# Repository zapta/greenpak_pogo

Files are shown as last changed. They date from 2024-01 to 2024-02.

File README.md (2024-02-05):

# GreenPAK Programming Pogo Probe

This project provides a standard footprint and a Pogo Probe for in-circuit programming of Renesas GreenPAK 
devices. This can be used for example in production after populating the board with factory reset GreenPAK devices.

<br>

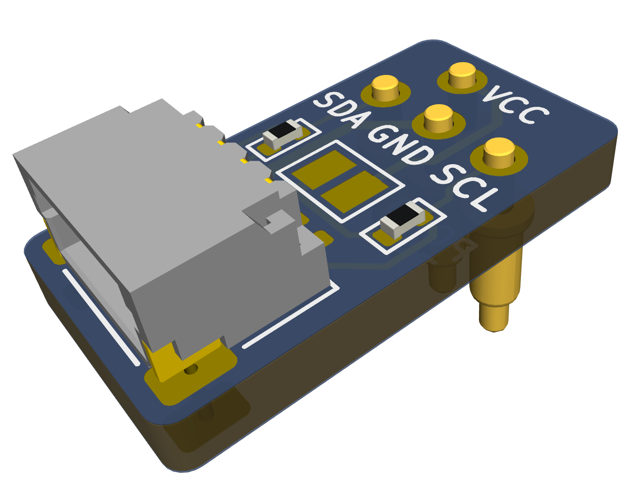
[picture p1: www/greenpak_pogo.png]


Highlights:

* Small footprint.
* In expensive (e.g. compared to Tag Connect)
* Can be used with any QWIIC masters as a probrammer.
* Can provide power to the programmed device.
* A single programming socket can support multiple GreenPAK devices on the same board.

# Schematic

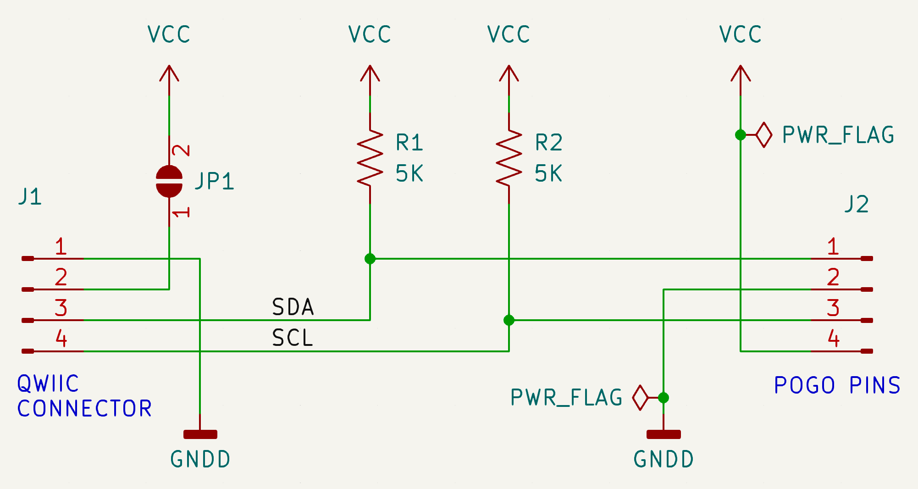
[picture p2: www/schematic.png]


# Pogo pins

We use common pogo pins from Aliexpress, the 5mm ones from https://www.aliexpress.us/item/3256803830386881.html. The diagram belows shows the advertised dimensions on Aliexpress, note that there are two 3.5mm dimensions, the longer of the two is actually 5mm. Also, the diameter of the base is 2mm.

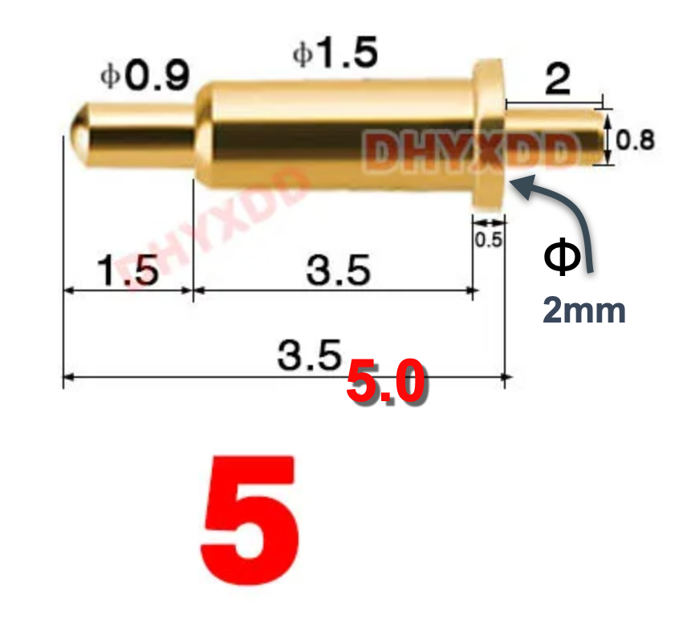
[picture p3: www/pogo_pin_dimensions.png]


# Connector

The connector is JST SH 1.0mm 4pin, SMD, horizontal, and is common on Aliexpress as well as short cables with matching QWIIC connectors on both ends. This is the same connector that is used by the QWIIC and STEMMA QT eco system and follows their pinout.  

| :warning: WARNING          |
|:---------------------------|
| The connecor follows the QWIIC pinout conventions and which are different from the pinout of the Renesas programmer.  If you are using the Pogo Probe with the Renesas programmer, pay attention to the wiring.    |

# Power jumper

The solder jumper on the Pogo Probe allows to connect or disconnect the VCC power of the programmer and the programmed board. By default it's disconnected and if needed, you can connect it with a drop of solder. 

# Pullup resistors

The Pogo Probe has two footprints for pullup resistors for the SDA and SCL signals respectivly. Populating them with 5K to 10K 0402 resistors should work well in most cases. If the circuit being programmed or the I2C master used to program already contain pullup resistors (it should, since the SDA and SCL GreenPAK inputs are not pulled up internally), they can be ommited.

# Programming socket

Kicad comaptible symbol and footprint for the programming socket are available in the kicad directory of this repository.

<br>

Schematic symbol:

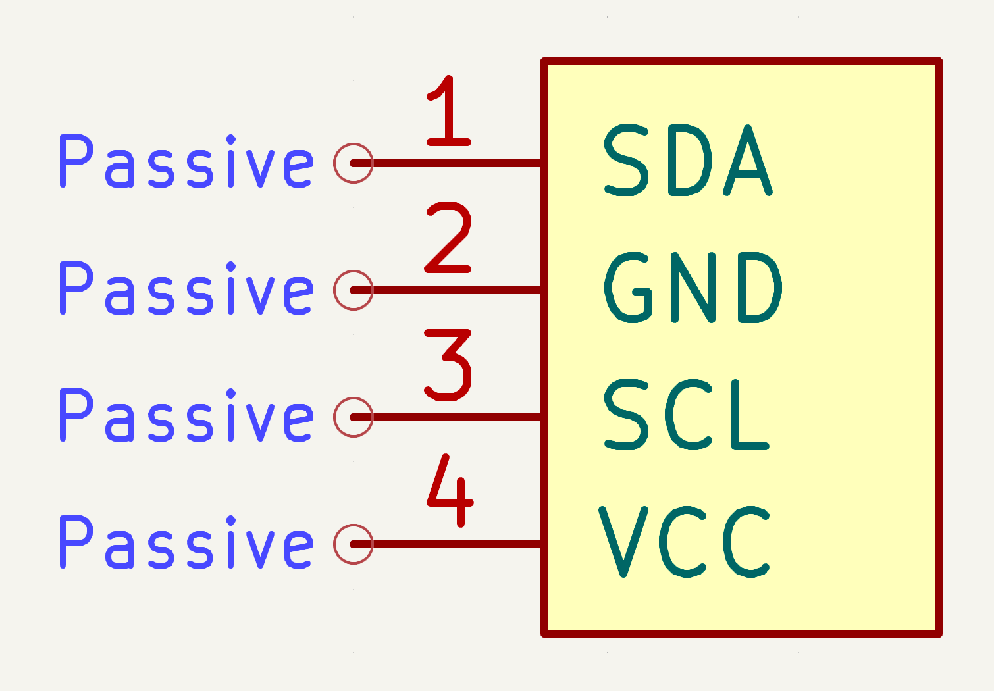
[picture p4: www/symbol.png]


<br>

PCB footprint:

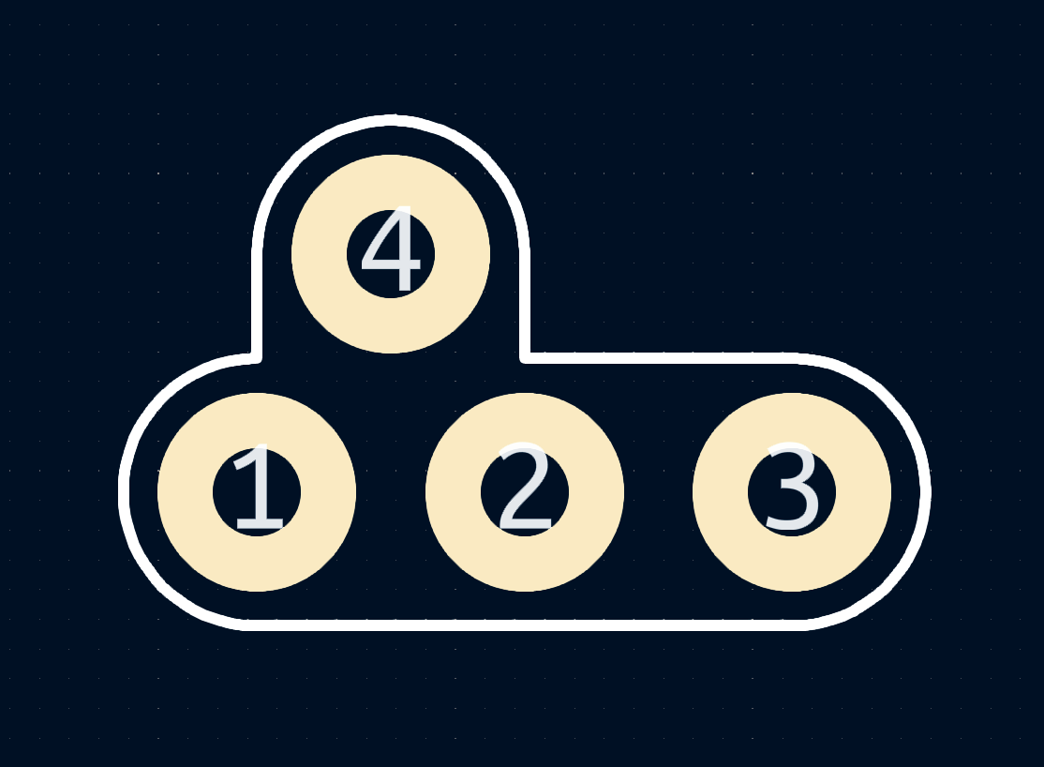
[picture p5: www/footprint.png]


<br>

PCB pads dimensions:

    

Top view, in mm. 

# Programming

We use a boards that are compatible with the Python ``i2c_adapter`` packge and the Python ``greenpak`` to program the boards. For example, if you use the SparkFun Pro Micro - RP2040 which contains a QWIIC connector, you can use a standard QWIIC cable to connect it to the Pogo Probe. Programming typically taks about 1 sec such that placing and holding the probe and hitting the program key is straight forward.

# Pin pattern

This pin patter was selected with these goals

* Small footprint.
* Non symetric, with only one 'right way' to connect it.
* Rounded dimensions in mm, vs mills. Introduced in V02.

# PCB order

The gerber file of the Pogo Probe is available under the JLCPCB directory. Smaller boards like this typically benefit from a thinner PCB (e.g. 1mm instead of 1.6mm) but we use 1.6mm for better mechanical support and easier holding.

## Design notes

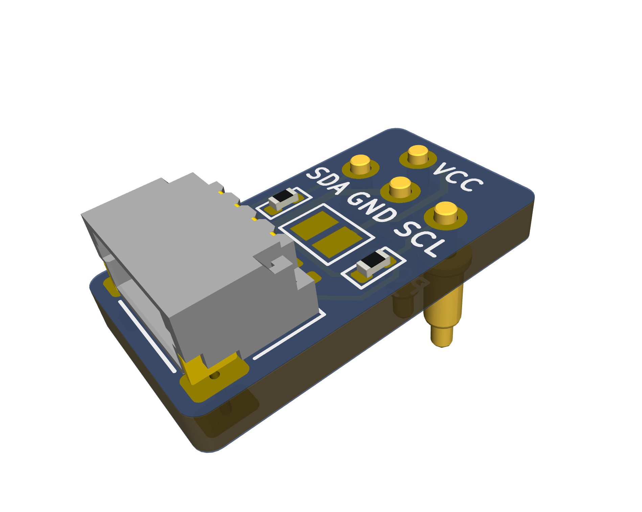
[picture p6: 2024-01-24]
kicad/greenpak_pogo.png

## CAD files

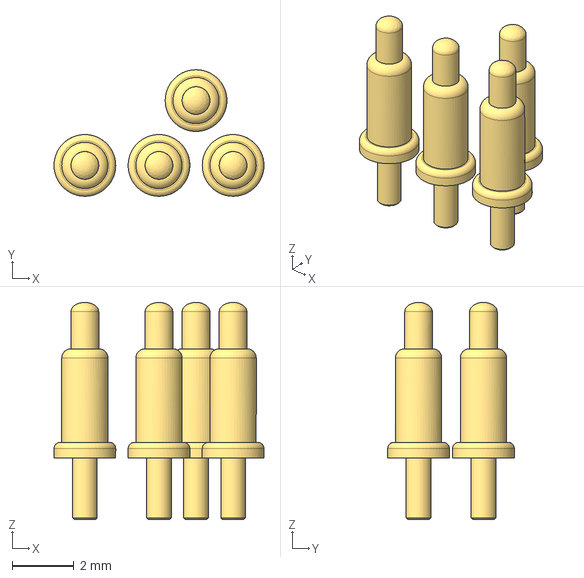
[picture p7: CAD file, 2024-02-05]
kicad/3d_models/POGO_PINS.step
6.80 x 4.10 x 7.03 mm

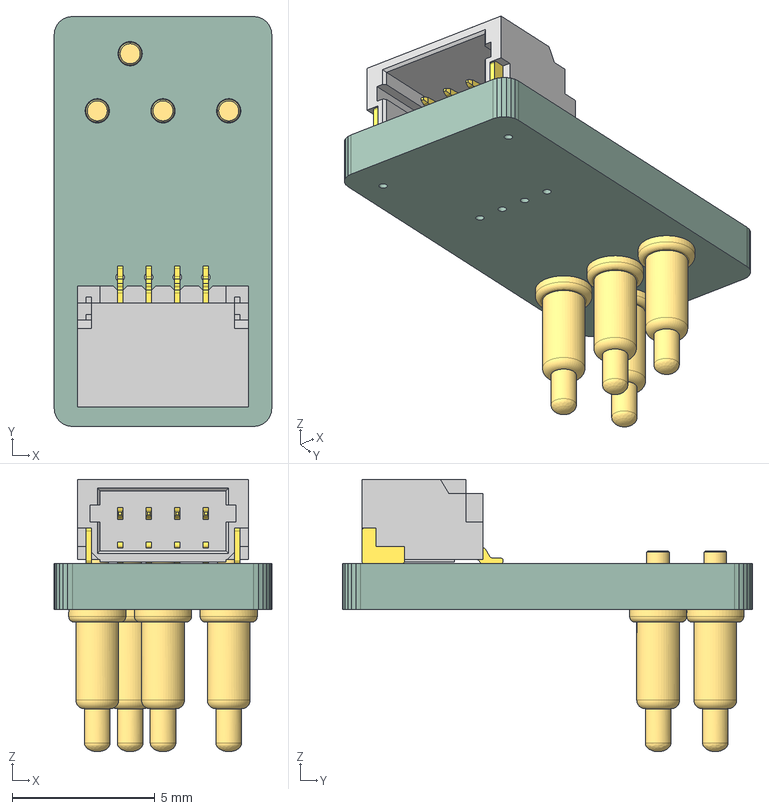
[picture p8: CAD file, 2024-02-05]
kicad/greenpak_pogo.step
7.62 x 14.4 x 9.53 mm
SMxB-SRSS-TB x 7
greenpak_pogo PCB

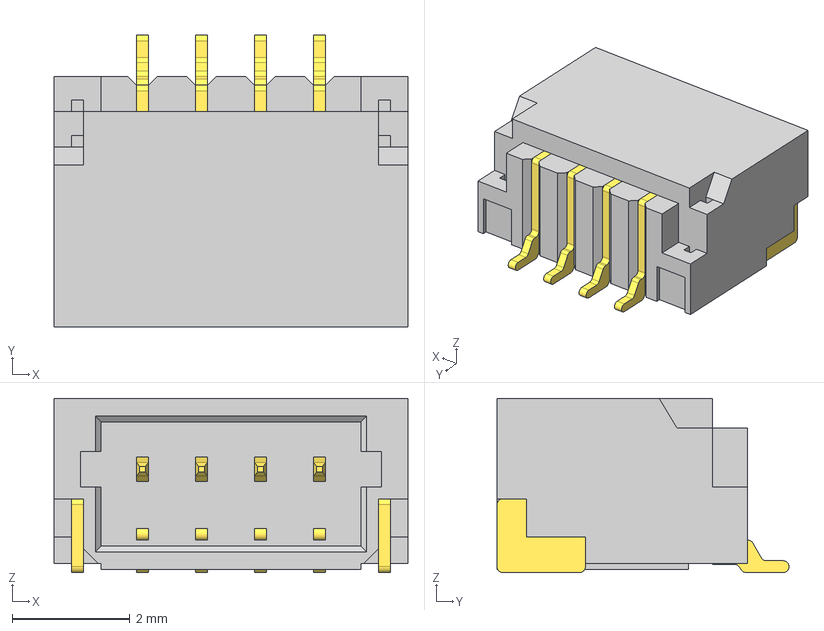
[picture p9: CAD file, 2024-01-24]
kicad/3d_models/SM4B-SRSS-TB.step
6.00 x 4.95 x 2.95 mm

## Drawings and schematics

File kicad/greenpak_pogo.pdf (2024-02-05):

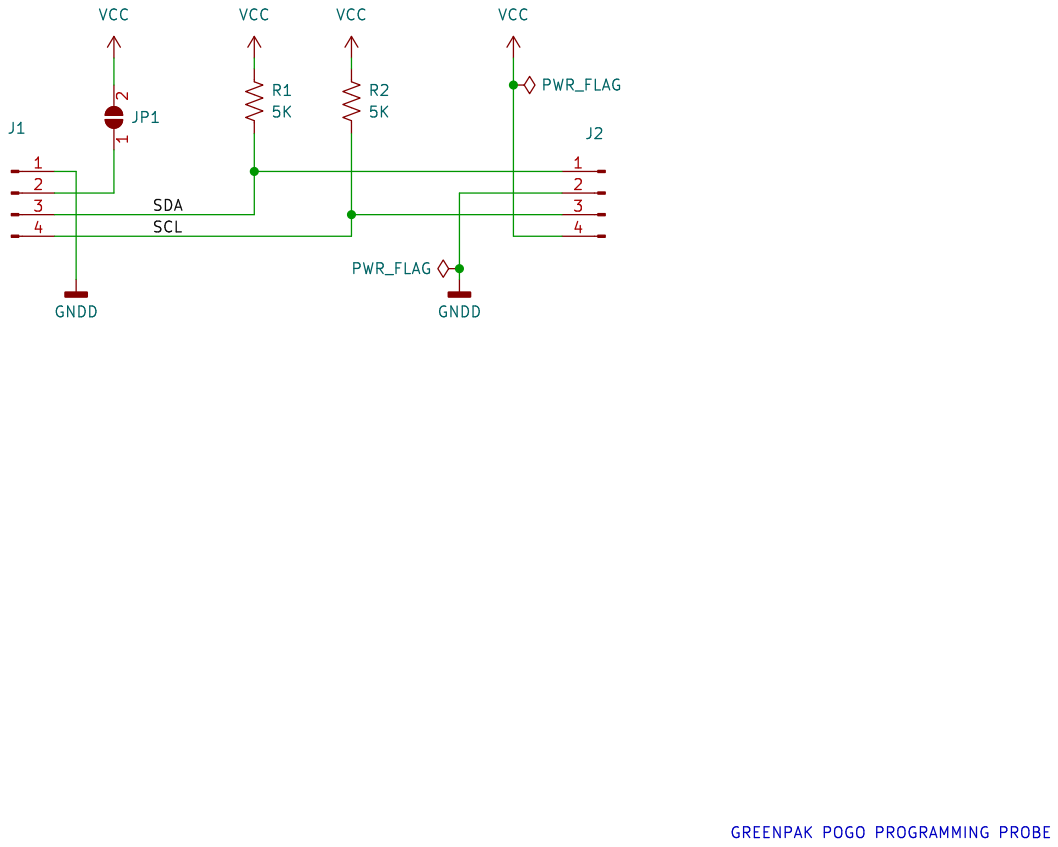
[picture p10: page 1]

1 2 JP1SCL SDA GREENPAK POGO PROGRAMMING PROBE

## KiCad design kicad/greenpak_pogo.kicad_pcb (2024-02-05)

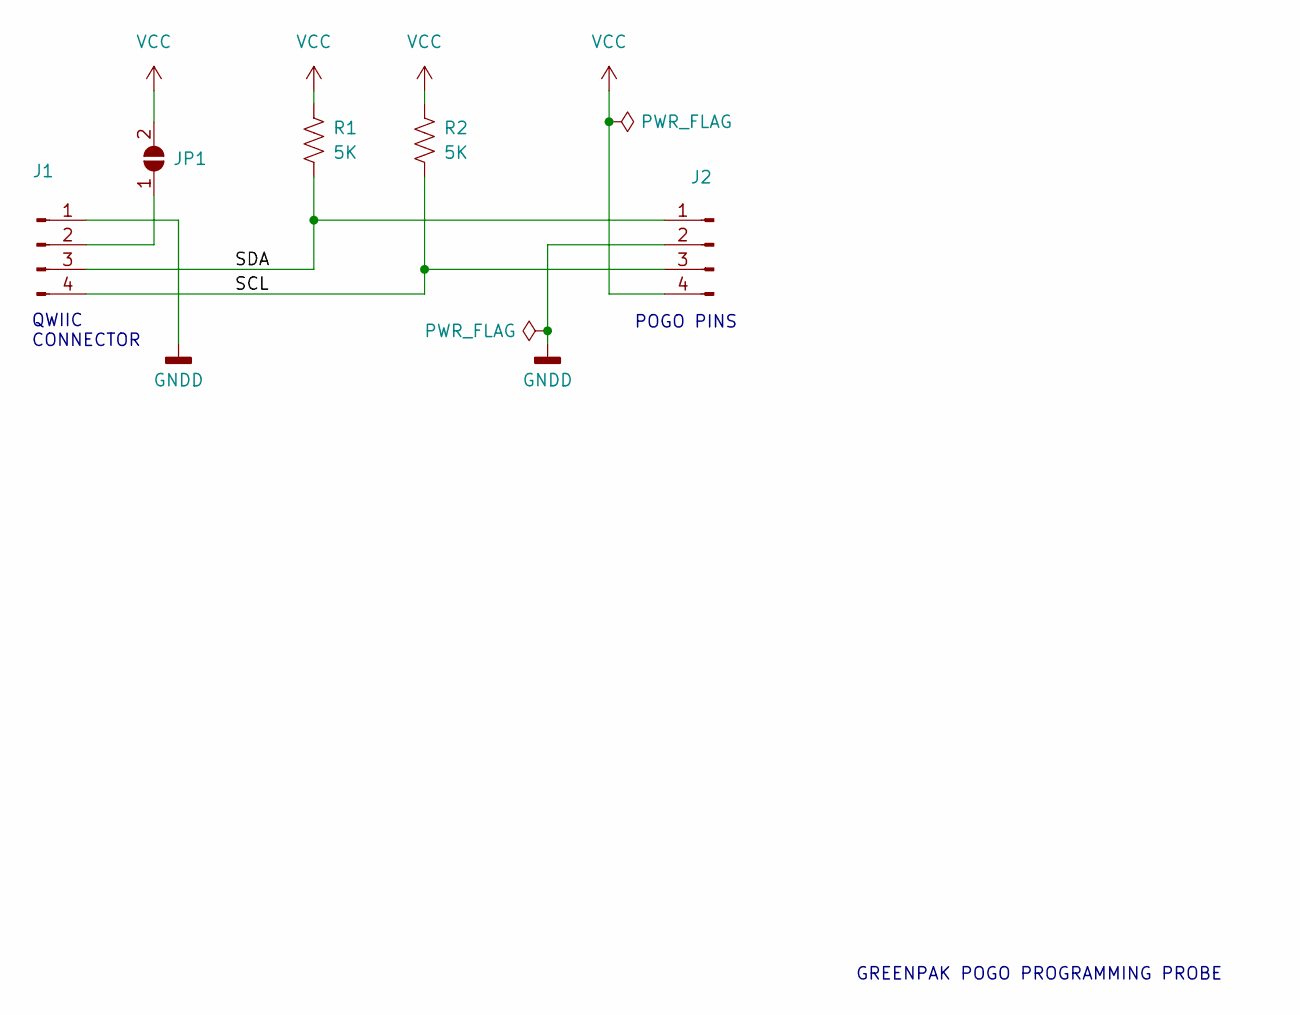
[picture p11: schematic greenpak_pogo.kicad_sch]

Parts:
J1: JST_SH_SM04B-SRSS-TB_1x04-1MP_P1.00mm_Horizontal
J2: GREENPAK_POGO_PINS
JP1: SOLDER_JUMPER
R1, R2: 5K; R_0402_1005Metric

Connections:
/SCL: J1.4, J2.3, R2.2
/SDA: J1.3, J2.1, R1.2
GNDD: J1.1, J2.2
unnamed: J1.2, JP1.1 (A)
VCC: J2.4, JP1.2 (B), R1.1, R2.1

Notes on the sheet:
GREENPAK POGO PROGRAMMING PROBE
QWIIC CONNECTOR
POGO PINS

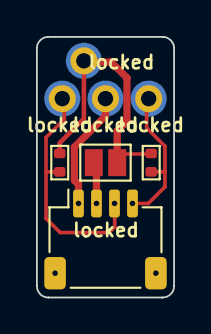
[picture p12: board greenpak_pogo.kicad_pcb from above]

Board: 2 copper layers, 7.6 x 14.5 mm, 6 parts (1 on the bottom side), 5 nets.

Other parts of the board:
G*: LOGO; QWIIC_logo_6mm

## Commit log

2024-01-24 Moved pogo directory to the new repository.
    [greenpak_pogo.kicad_pcb]
2024-01-24 Cleaned up post project name change to greenpak_pogo.
    [greenpak_pogo.kicad_pcb]
2024-01-24 Added 3D models.
    [BM4B-SRSS-TB.step, SM4B-SRSS-TB.step, greenpak_pogo.kicad_pcb]
2024-01-24 Fixed the appearance of the QWIIC connector 3d model.
    [SM4B-SRSS-TB.step]
2024-01-24 Added 3d models of pins.
    [BM4B-SRSS-TB.step, POGO_PINS.step, greenpak_pogo.kicad_pcb]
2024-01-24 Tweak the pogo PCB boundary.
    [greenpak_pogo.kicad_pcb]
2024-01-24 Added pcb rendering.
2024-01-24 Added to the pogo probe pullup resistors.
    [greenpak_pogo.kicad_pcb]
2024-02-05 Updated pogo socket to new dimensions.
    [POGO_PINS.step, greenpak_pogo.kicad_pcb, greenpak_pogo.step]
2024-02-05 Added schematic.
    [greenpak_pogo.kicad_pcb, greenpak_pogo.kicad_sch]
2024-02-05 Generated gervers.
    [greenpak_pogo.kicad_pcb]
2024-02-05 Added schematic to the doc.
    [greenpak_pogo.kicad_sch]
2024-02-05 Increased VCC trace width and regenerated gerbers.
    [greenpak_pogo.kicad_pcb]
2024-02-05 Tweaked the silkscreen of the pogo socket.
